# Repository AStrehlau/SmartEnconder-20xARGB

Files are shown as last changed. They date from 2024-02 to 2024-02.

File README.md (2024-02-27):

# SmartEncoder-20xARGB

This "SmartEncoder" uses 20 adressable LEDs (SK6805-EC15 or potentially XL-1615RGBC-WS2812B) to visualize the set point of the encoder. The SmartEncoder boasts WiFi and Bluetooth capability using the ESP32, which makes it viable for Smart Home and PC control applications.<br>
It should be noted that stock Windows does not normally have the capability to send the current volume level over BT, which is why a PC side software to take care of that will be uploaded  in the future for use as a BT PC volume knob.

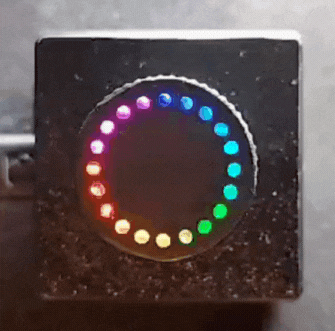
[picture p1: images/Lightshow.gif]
Lightshow


## Hardware

You can directly order the three PCBs needed for this project using the Gerber files (generated for JLCPCB but likely to work with most common providers) or modify the PCB files at your discretion and generate new Gerber files.

Each of the three PCBs have to be completely assembled before they can be stacked in the correct order using the 3D printed spacers and either wire or very long headers. For the assembly of the Top/LED PCB it is recommended if not necessary to order a stencil with the PCBs. The other PCBs can be assembled without one if so desired.

There is a complete BOM (except the very long headers/wire and M3x25m screws!) for all three PCBs and an interactive BOM for the PCB with the ESP32 on it. There is no ibom for the other two PCBs since every capacitor used on them is 100nF, every resistor on the encoder PCB is 10k and the one resistor on the LED PCB is 330R as can be seen in the schematics.<br>
The EMI filter on the ESP32 PCB (L1, L2 and C4) can be left out and Jumper JP1 soldered instead, although it is not recommended. Doing this has no effect on the functionality.<br>
Especially if you don't plan on running intensive animations on the LEDs the 20 bypass capacitors are definitely overkill (even though the datasheet might disagree). If you want to save on parts/ time spent placing them you can just place C14, C15 and C16 which was more than enough in my testing even just one of them might work for you.

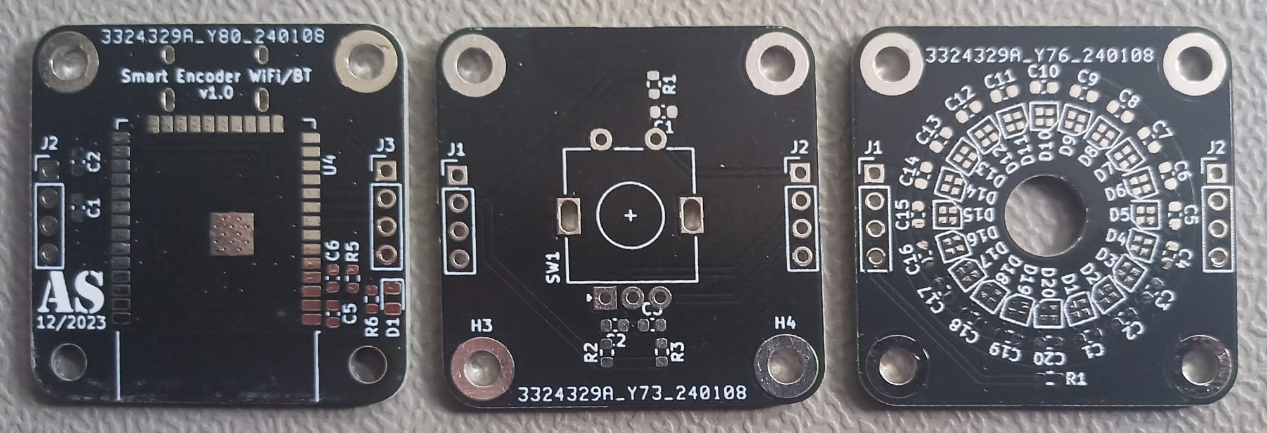
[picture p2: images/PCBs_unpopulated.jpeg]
Unpopulated PCBs


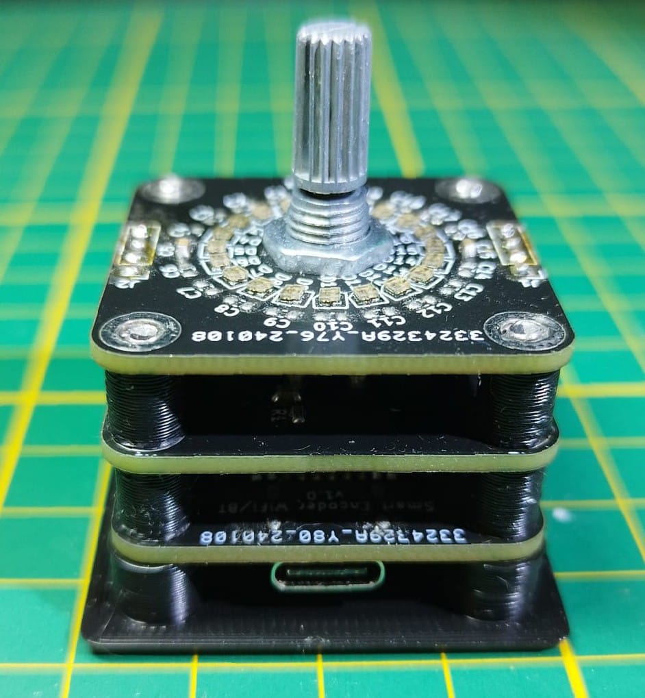
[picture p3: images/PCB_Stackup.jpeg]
PCBStackup


## 3D printed case

Thanks to [Nedos on Thingiverse](https://www.thingiverse.com/thing:6506406) designing a case including two knob versions for you to choose from and anti-bleed part for this project you can simply download the files and print them.<br>
The holes in the knob are meant to be filled with regular 1.75mm diameter transparent filament and either both surfaces cut flush using a side cutter or even sanded down for a better look.<br>
The anti-bleed part can simply be put on the LEDs making sure not to damage them.<br>
For assembly you only need the printed parts including spacers and M3x25mm screws, preferably with a flat underside.

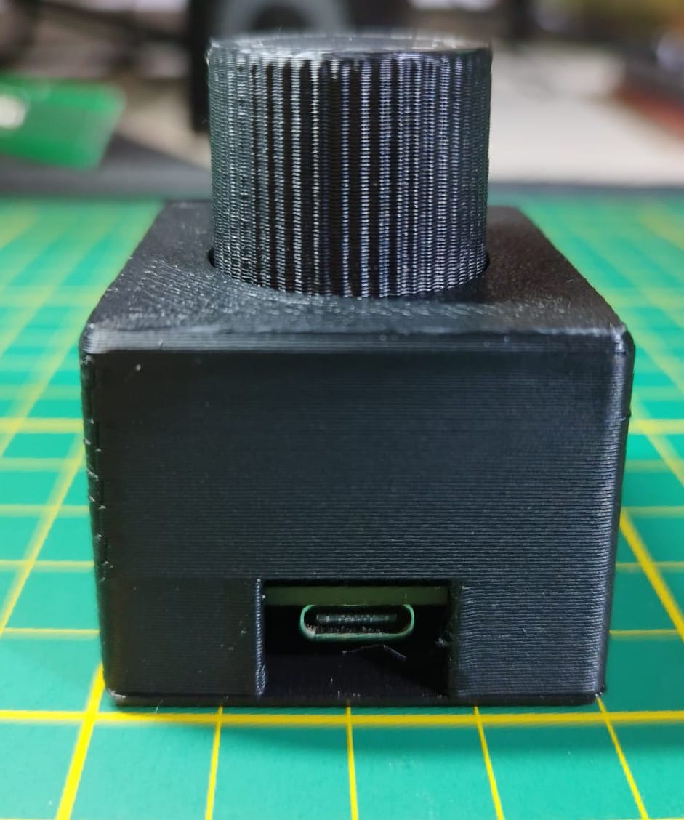
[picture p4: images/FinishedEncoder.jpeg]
Finished Encoder


## Software 

Because of layout reasons the LEDs have to be addressed in the opposite than expected order (LED number on the silkscreen is correct) which can result in longer code depending on the application.

There is a demo code for the LEDs which is just a slightly modified version of the Adafruit NEOPIXEL "strandtest" example to check if the LEDs are soldered correctly and undamaged as well as to give you a nice lightshow as can be seen at the top.<br>
This code can be flashed onto the ESP32 using the Arduino IDE.

Also available is a ESPHome configuration to integrate the SmartEncoder into HomeAssistant.

WIP: Code for ESP and PC to communicate via Serial over Bluetooth to use as a volume knob with accurate volume display on the SmartEncoder side

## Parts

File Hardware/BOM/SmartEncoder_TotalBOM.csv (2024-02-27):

Id | Footprint | Quantity | Designation | Supplier and ref
1 | R_0603_1608Metric | 6 | 10k
2 | C_0603_1608Metric | 3 | 1uF/10V/X5R
3 | C_0603_1608Metric | 24 | 100nF/10V/X7R
4 | ESP32-WROOM-32D | 1 | ESP32-WROOM-32D |  | NOTE: any ESP32-WROOM-32x works
5 | R_0603_1608Metric | 1 | 1k
6 | LED_0805_2012Metric | 1 | BLUE
7 | C_0603_1608Metric | 2 | 22uF/10V/X5R
8 | USB_C_Receptacle_HRO_TYPE-C-31-M-12 | 1 | USB_C_Receptacle_USB2.0 | SHOU HAN TYPE-C 16PIN 2MD(073)
9 | SolderJumper-2_P1.3mm_Open_RoundedPad1.0x1.5mm | 1 | SolderJumper_2_Open
10 | SOT-23-3 | 2 | MMBT4401
11 | R_0603_1608Metric | 1 | 15k
12 | L_0805_2012Metric | 2 | WLBD2012HCU601TH | WLBD2012HCU601TH or SBH2012S601NSP | SBH2012S601NSP is cheaper
13 | R_0603_1608Metric | 1 | 68k
14 | SOT-23-5 | 1 | M3406
15 | L_Abracon_ASPI-4030S | 1 | 2.2uH | SWPA4030S2R2
16 | SOIC-16_3.9x9.9mm_P1.27mm | 1 | CH340C
17 | R_0603_1608Metric | 2 | 5.1k
18 | RotaryEncoder_Alps_EC11E-Switch_Vertical_H20mm | 1 | RotaryEncoder_Switch |  | EC11 20mm „plum handle“
19 | SK6805-EC15 | 20 | SK6805-EC15 |  | NOTE: XL-1615RGBC-WS2812B !might! Work too and is cheaper
20 | R_0603_1608Metric | 1 | 330R

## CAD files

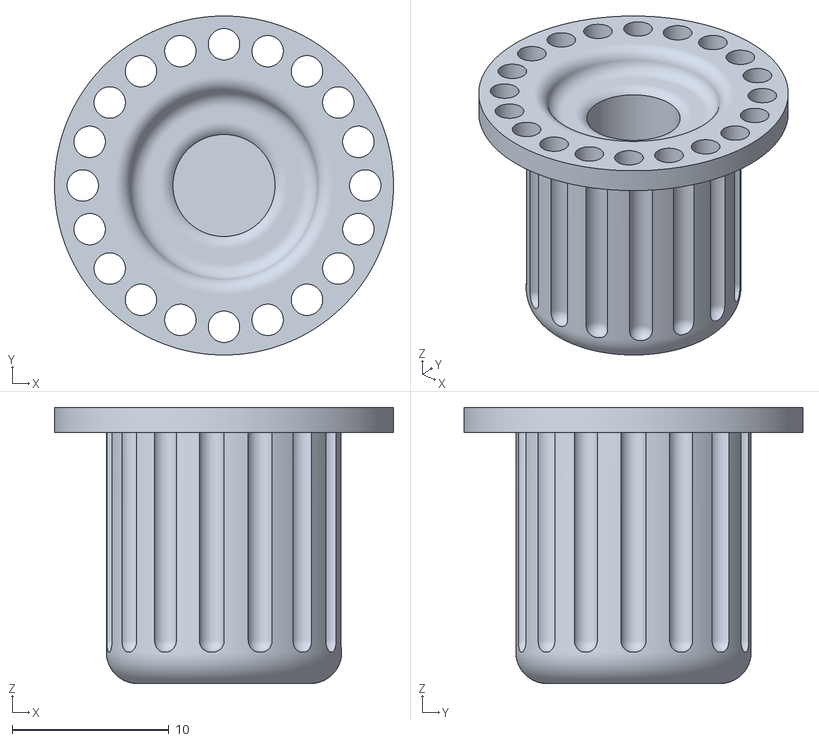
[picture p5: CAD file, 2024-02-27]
3D/KnobSmall.stl
21.6 x 21.6 x 17.6

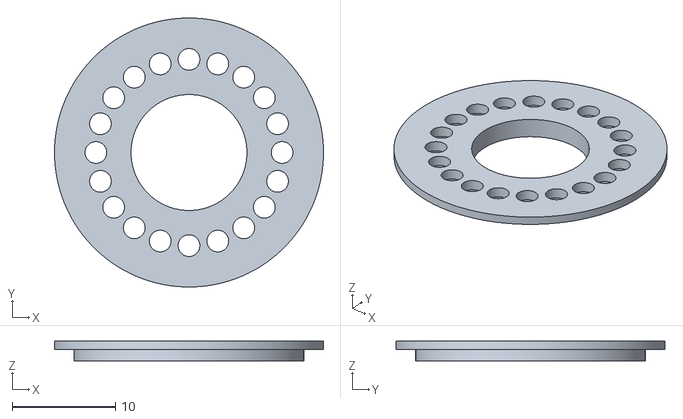
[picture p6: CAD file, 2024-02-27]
3D/AntiBleed.stl
26.0 x 26.0 x 1.90

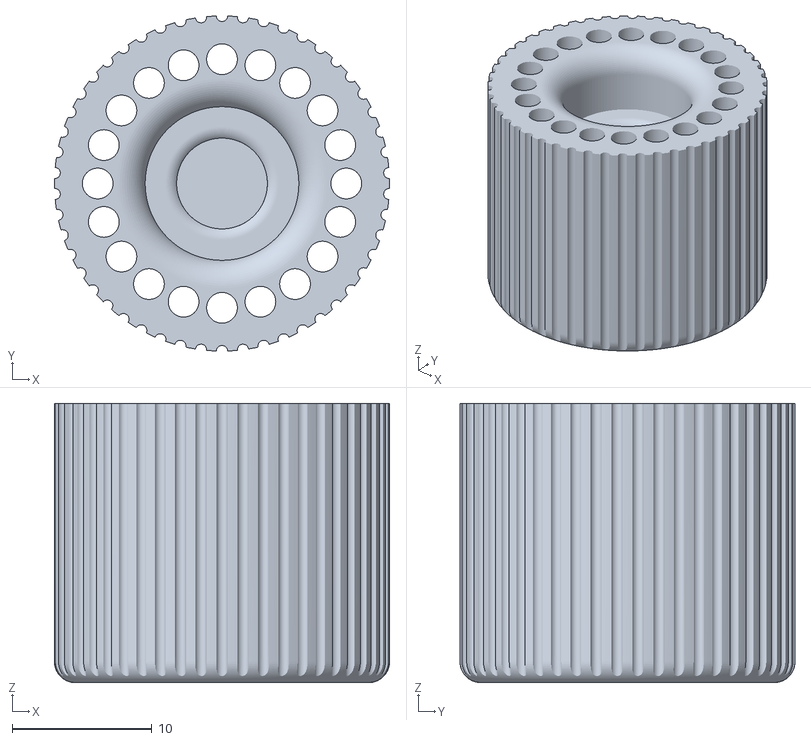
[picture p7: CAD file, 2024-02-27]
3D/KnobBig.stl
24.0 x 24.0 x 20.0

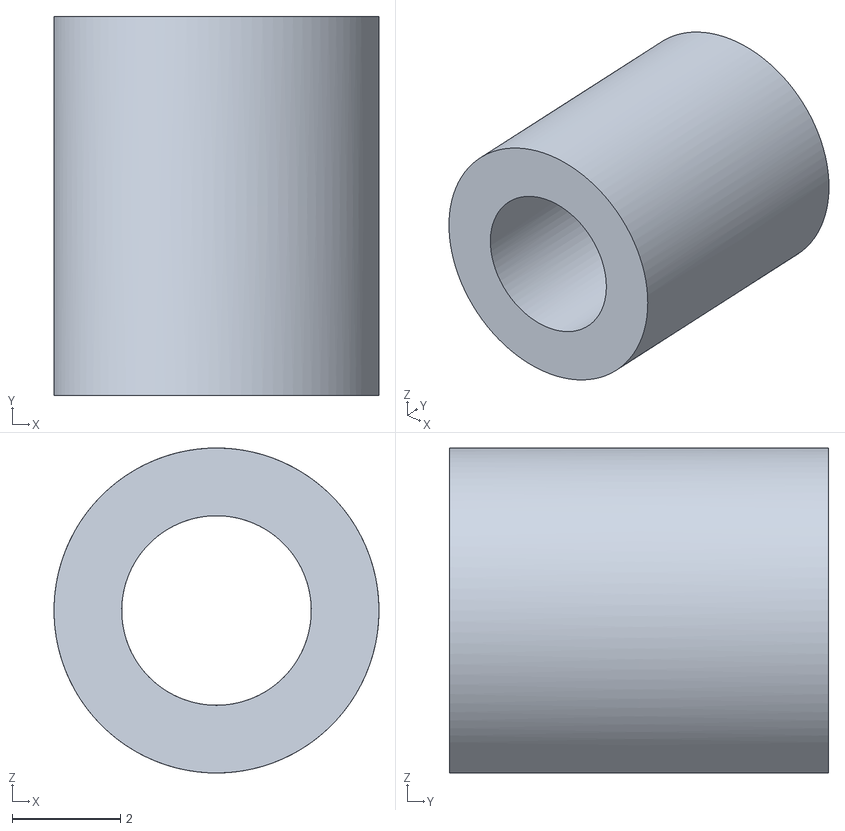
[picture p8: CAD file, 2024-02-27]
3D/Spacerx8.stl
6.00 x 7.00 x 6.00

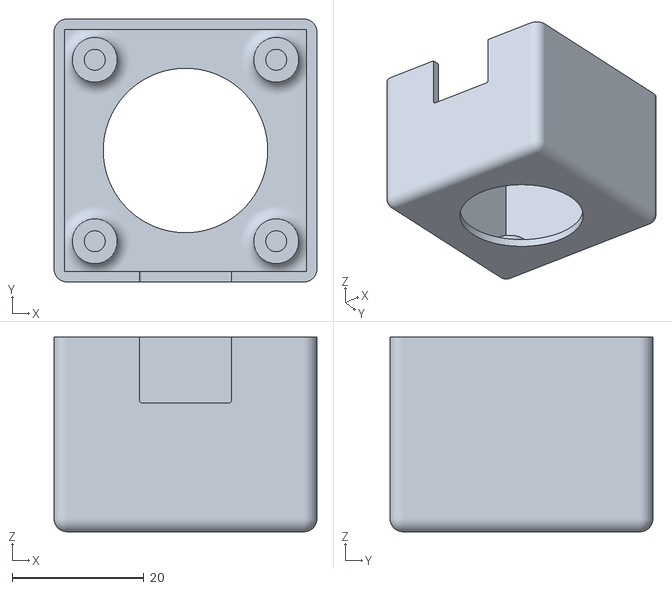
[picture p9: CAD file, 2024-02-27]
3D/SmartEncoderCase.stl
40.0 x 40.0 x 29.6

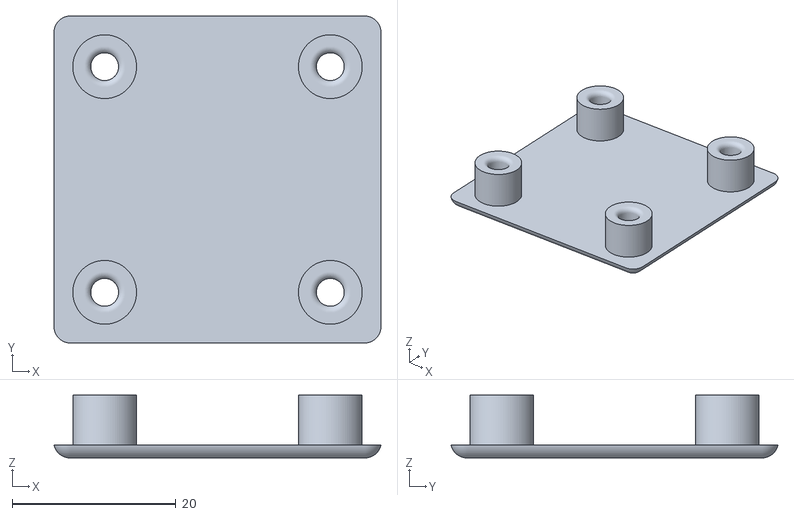
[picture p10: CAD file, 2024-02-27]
3D/SmartEncoderLid.stl
40.0 x 40.0 x 7.70

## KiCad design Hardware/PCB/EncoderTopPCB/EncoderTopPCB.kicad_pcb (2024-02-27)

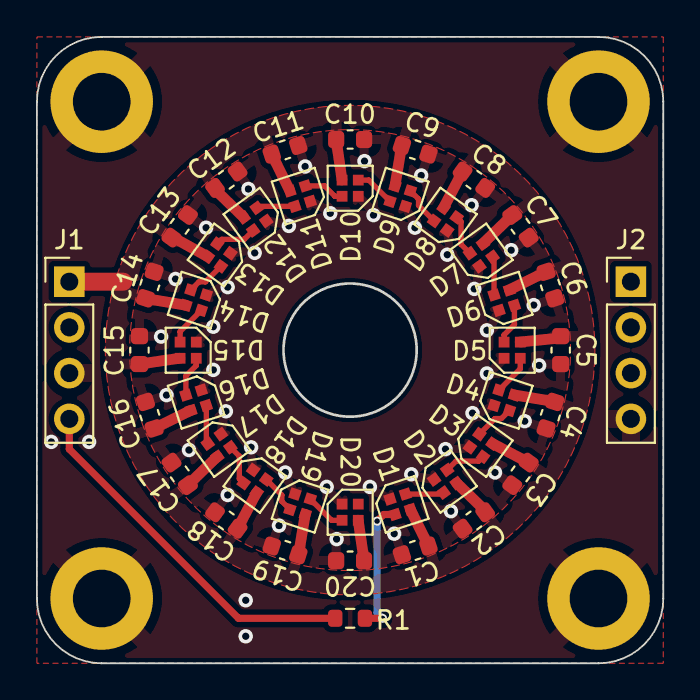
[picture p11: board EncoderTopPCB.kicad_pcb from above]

Board: 2 copper layers, 34.8 x 34.8 mm, 47 parts (0 on the bottom side), 23 nets.

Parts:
C1, C2, C3, C4, C5, C6, C7, C8, C9, C10, C11, C12, C13, C14, C15, C16, C17, C18, C19, C20: 10V/100nF/X7R; C_0603_1608Metric
D1, D2, D3, D4, D5, D6, D7, D8, D9, D10, D11, D12, D13, D14, D15, D16, D17, D18, D19, D20: SK6805; SK6805-EC15
H1, H2, H3, H4: DNP; MountingHole_3.2mm_M3_ISO7380_Pad
J1, J2: DNP; PinHeader_1x04_P2.54mm_Vertical
R1: 330R; R_0603_1608Metric

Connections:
+5V: C1.1, C2.1, C3.1, C4.1, C5.1, C6.1, C7.1, C8.1, C9.1, C10.1, C11.1, C12.1, C13.1, C14.1, C15.1, C16.1, C17.1, C18.1, C19.1, C20.1, D1.2 (VDD), D2.2 (VDD), D3.2 (VDD), D4.2 (VDD), D5.2 (VDD), D6.2 (VDD), D7.2 (VDD), D8.2 (VDD), D9.2 (VDD), D10.2 (VDD), D11.2 (VDD), D12.2 (VDD), D13.2 (VDD), D14.2 (VDD), D15.2 (VDD), D16.2 (VDD), D17.2 (VDD), D18.2 (VDD), D19.2 (VDD), D20.2 (VDD), J1.1
GND: C1.2, C2.2, C3.2, C4.2, C5.2, C6.2, C7.2, C8.2, C9.2, C10.2, C11.2, C12.2, C13.2, C14.2, C15.2, C16.2, C17.2, C18.2, C19.2, C20.2, D1.4 (VSS), D2.4 (VSS), D3.4 (VSS), D4.4 (VSS), D5.4 (VSS), D6.4 (VSS), D7.4 (VSS), D8.4 (VSS), D9.4 (VSS), D10.4 (VSS), D11.4 (VSS), D12.4 (VSS), D13.4 (VSS), D14.4 (VSS), D15.4 (VSS), D16.4 (VSS), D17.4 (VSS), D18.4 (VSS), D19.4 (VSS), D20.4 (VSS), H1.1, H2.1, H3.1, H4.1, J1.3, J2.4
IO3: J1.4, R1.1
unnamed: D1.1 (DIN), R1.2
unnamed: D1.3 (DOUT), D2.1 (DIN)
unnamed: D2.3 (DOUT), D3.1 (DIN)
unnamed: D3.3 (DOUT), D4.1 (DIN)
unnamed: D4.3 (DOUT), D5.1 (DIN)
unnamed: D5.3 (DOUT), D6.1 (DIN)
unnamed: D6.3 (DOUT), D7.1 (DIN)
unnamed: D7.3 (DOUT), D8.1 (DIN)
unnamed: D8.3 (DOUT), D9.1 (DIN)
unnamed: D9.3 (DOUT), D10.1 (DIN)
unnamed: D10.3 (DOUT), D11.1 (DIN)
unnamed: D11.3 (DOUT), D12.1 (DIN)
unnamed: D12.3 (DOUT), D13.1 (DIN)
unnamed: D13.3 (DOUT), D14.1 (DIN)
unnamed: D14.3 (DOUT), D15.1 (DIN)
unnamed: D15.3 (DOUT), D16.1 (DIN)
unnamed: D16.3 (DOUT), D17.1 (DIN)
unnamed: D17.3 (DOUT), D18.1 (DIN)
unnamed: D18.3 (DOUT), D19.1 (DIN)
unnamed: D19.3 (DOUT), D20.1 (DIN)

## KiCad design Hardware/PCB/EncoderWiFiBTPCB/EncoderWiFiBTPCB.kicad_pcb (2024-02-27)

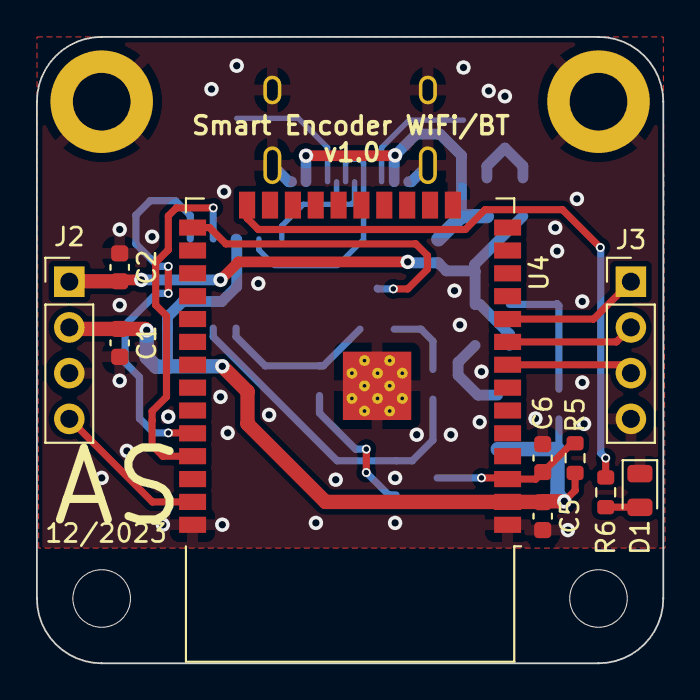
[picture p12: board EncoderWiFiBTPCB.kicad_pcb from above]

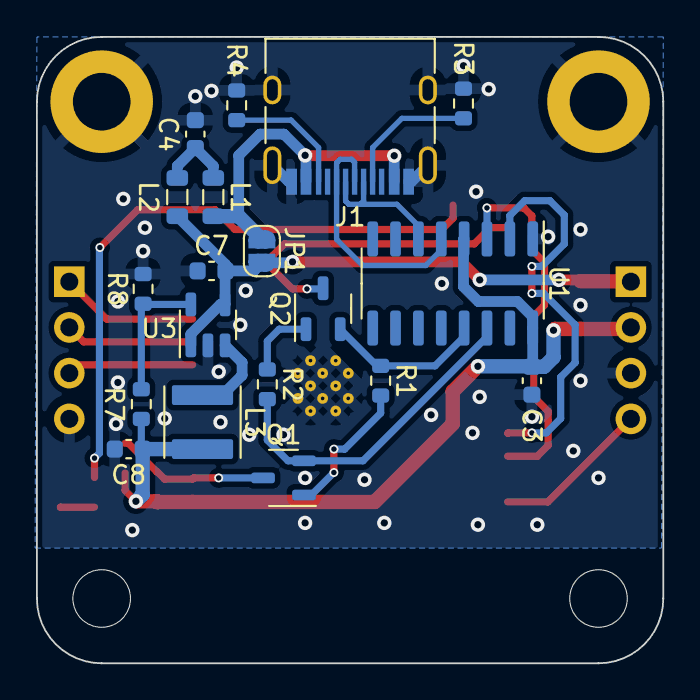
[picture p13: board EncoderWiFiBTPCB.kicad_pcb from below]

Board: 2 copper layers, 34.8 x 34.8 mm, 33 parts (19 on the bottom side), 25 nets.

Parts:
C1, C2, C4: 1uF/25V/X5R; C_0603_1608Metric
C3, C5, C6: 100nF/10V/X7R; C_0603_1608Metric
C7, C8: 22uF/10V/X5R; C_0603_1608Metric
D1: BLUE; LED_0805_2012Metric
H1, H2: MountingHole_Pad; MountingHole_3.2mm_M3_ISO7380_Pad
H3, H4: MountingHole; MountingHole_3.2mm_M3_ISO7380
J1: USB_C_Receptacle_USB2.0; USB_C_Receptacle_HRO_TYPE-C-31-M-12
J2, J3: Conn_01x04_Pin; PinHeader_1x04_P2.54mm_Vertical
JP1: SolderJumper_2_Open; SolderJumper-2_P1.3mm_Open_RoundedPad1.0x1.5mm
L1, L2: WLBD2012HCU601TH; L_0805_2012Metric
L3: 2.2uH; L_Abracon_ASPI-4030S
Q1, Q2: MMBT4401; SOT-23-3
R1, R2, R5: 10k; R_0603_1608Metric
R3, R4: 5.1k; R_0603_1608Metric
R6: 1k; R_0603_1608Metric
R7: 68k; R_0603_1608Metric
R8: 15k; R_0603_1608Metric
U1: CH340C; SOIC-16_3.9x9.9mm_P1.27mm
U3: M3406; SOT-23-5
U4: ESP32-WROOM-32D

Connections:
+3V3: C1.1, C3.1, C5.2, C8.1, J2.2, L3.2, R5.2, R7.1, U1.4 (V3), U1.16 (VCC), U4.2 (VDD)
+5V: C2.1, C7.1, J2.1, JP1.2 (B), L2.2, U3.1 (RUN), U3.4 (VIN)
D+: J1.A6 (D+), J1.B6 (D+), U1.5 (UD+)
D-: J1.A7 (D-), J1.B7 (D-), U1.6 (UD-)
ENCODER_A: J3.2, U4.9 (IO33)
ENCODER_B: J3.3, U4.8 (IO32)
ENCODER_BTN: J3.1, U4.10 (IO25)
GND: C1.2, C2.2, C3.2, C4.2, C5.1, C6.1, C7.2, C8.2, D1.1 (K), H1.1, H2.1, J1.A1 (GND), J1.A12 (GND), J1.B1 (GND), J1.B12 (GND), J1.S1 (SHIELD), J2.3, J3.4, R3.2, R4.2, R8.2, U1.1 (GND), U3.2 (GND), U4.1 (GND), U4.15 (GND), U4.38 (GND), U4.39 (GND)
IO23: J2.4, U4.37 (IO23)
unnamed: C4.1, L1.2, L2.1
unnamed: D1.2 (A), R6.1
unnamed: J1.A5 (CC1), R3.1
unnamed: J1.B5 (CC2), R4.1
unnamed: J1.A4 (VBUS), J1.A9 (VBUS), J1.B4 (VBUS), J1.B9 (VBUS), JP1.1 (A), L1.1
unnamed: Q1.1 (B), R1.2
unnamed: Q1.2 (E), R2.1, U1.14 (~RTS)
unnamed: Q2.1 (B), R2.2
unnamed: Q2.2 (E), R1.1, U1.13 (~DTR)
unnamed: R7.2, R8.1, U3.5 (FB)
unnamed: L3.1, U3.3 (SW)
unnamed: R6.2, U4.24 (IO2)
RX0 (Programming): U1.2 (TXD), U4.34 (RXD0/IO3)
TX0 (Programming): U1.3 (RXD), U4.35 (TXD0/IO1)
~BOOTMODE: Q2.3 (C), U4.25 (IO0)
~RST: C6.2, Q1.3 (C), R5.1, U4.3 (EN)

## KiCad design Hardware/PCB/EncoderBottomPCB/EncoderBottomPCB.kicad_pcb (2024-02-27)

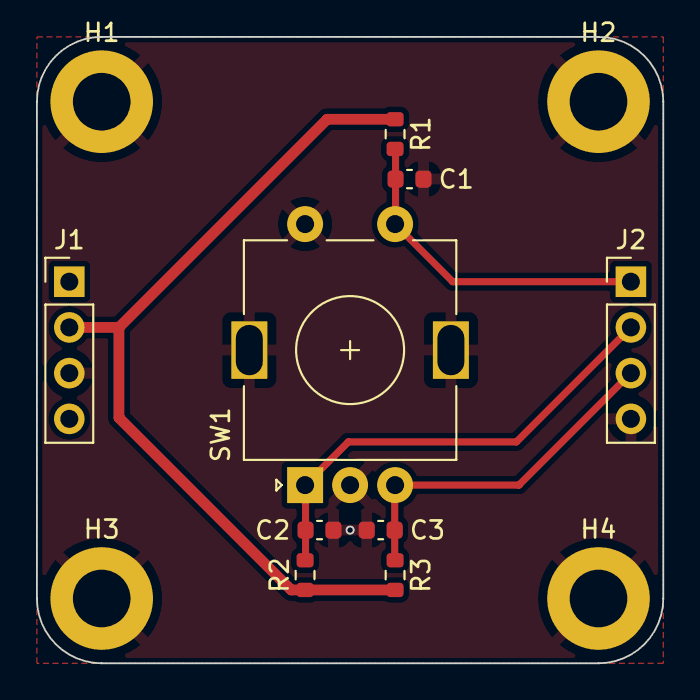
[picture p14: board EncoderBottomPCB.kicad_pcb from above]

Board: 2 copper layers, 34.8 x 34.8 mm, 13 parts (0 on the bottom side), 5 nets.

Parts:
C1, C2, C3: 100nF/10V/X7R; C_0603_1608Metric
H1, H2, H3, H4: MountingHole_Pad; MountingHole_3.2mm_M3_ISO7380_Pad
J1, J2: Conn_01x04_Pin; PinHeader_1x04_P2.54mm_Vertical
R1, R2, R3: 10k; R_0603_1608Metric
SW1: RotaryEncoder_Switch; RotaryEncoder_Alps_EC11E-Switch_Vertical_H20mm

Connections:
+3V3: J1.2, R1.1, R2.1, R3.2
ENCODER_A: C2.2, J2.2, R2.2, SW1.A
ENCODER_B: C3.2, J2.3, R3.1, SW1.B
ENCODER_BTN: C1.2, J2.1, R1.2, SW1.S1
GND: C1.1, C2.1, C3.1, H1.1, H2.1, H3.1, H4.1, J1.3, J2.4, SW1.C, SW1.MP, SW1.S2

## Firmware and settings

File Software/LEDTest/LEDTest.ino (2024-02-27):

// A basic everyday NeoPixel strip test program.

// NEOPIXEL BEST PRACTICES for most reliable operation:
// - Add 1000 uF CAPACITOR between NeoPixel strip's + and - connections.
// - MINIMIZE WIRING LENGTH between microcontroller board and first pixel.
// - NeoPixel strip's DATA-IN should pass through a 300-500 OHM RESISTOR.
// - AVOID connecting NeoPixels on a LIVE CIRCUIT. If you must, ALWAYS
//   connect GROUND (-) first, then +, then data.
// - When using a 3.3V microcontroller with a 5V-powered NeoPixel strip,
//   a LOGIC-LEVEL CONVERTER on the data line is STRONGLY RECOMMENDED.
// (Skipping these may work OK on your workbench but can fail in the field)

#include <Adafruit_NeoPixel.h>
#ifdef __AVR__
 #include <avr/power.h> // Required for 16 MHz Adafruit Trinket
#endif

// Which pin on the Arduino is connected to the NeoPixels?
// On a Trinket or Gemma we suggest changing this to 1:
#define LED_PIN    23

// How many NeoPixels are attached to the Arduino?
#define LED_COUNT 20

// Declare our NeoPixel strip object:
Adafruit_NeoPixel strip(LED_COUNT, LED_PIN, NEO_GRB + NEO_KHZ800);
// Argument 1 = Number of pixels in NeoPixel strip
// Argument 2 = Arduino pin number (most are valid)
// Argument 3 = Pixel type flags, add together as needed:
//   NEO_KHZ800  800 KHz bitstream (most NeoPixel products w/WS2812 LEDs)
//   NEO_KHZ400  400 KHz (classic 'v1' (not v2) FLORA pixels, WS2811 drivers)
//   NEO_GRB     Pixels are wired for GRB bitstream (most NeoPixel products)
//   NEO_RGB     Pixels are wired for RGB bitstream (v1 FLORA pixels, not v2)
//   NEO_RGBW    Pixels are wired for RGBW bitstream (NeoPixel RGBW products)


// setup() function -- runs once at startup --------------------------------

void setup() {
  // These lines are specifically to support the Adafruit Trinket 5V 16 MHz.
  // Any other board, you can remove this part (but no harm leaving it):
#if defined(__AVR_ATtiny85__) && (F_CPU == 16000000)
  clock_prescale_set(clock_div_1);
#endif
  // END of Trinket-specific code.

  strip.begin();           // INITIALIZE NeoPixel strip object (REQUIRED)
  strip.show();            // Turn OFF all pixels ASAP
  strip.setBrightness(30); // Set BRIGHTNESS to about 1/5 (max = 255)
}


// loop() function -- runs repeatedly as long as board is on ---------------

void loop() {
  // Fill along the length of the strip in various colors...
  colorWipe(strip.Color(255,   0,   0), 50); // Red
  colorWipe(strip.Color(  0, 255,   0), 50); // Green
  colorWipe(strip.Color(  0,   0, 255), 50); // Blue

  // Do a theater marquee effect in various colors...
  theaterChase(strip.Color(127, 127, 127), 50); // White, half brightness
  theaterChase(strip.Color(127,   0,   0), 50); // Red, half brightness
  theaterChase(strip.Color(  0,   0, 127), 50); // Blue, half brightness

  rainbow(10);             // Flowing rainbow cycle along the whole strip
  theaterChaseRainbow(50); // Rainbow-enhanced theaterChase variant
}


// Some functions of our own for creating animated effects -----------------

// Fill strip pixels one after another with a color. Strip is NOT cleared
// first; anything there will be covered pixel by pixel. Pass in color
// (as a single 'packed' 32-bit value, which you can get by calling
// strip.Color(red, green, blue) as shown in the loop() function above),
// and a delay time (in milliseconds) between pixels.
void colorWipe(uint32_t color, int wait) {
  for(int i=0; i<strip.numPixels(); i++) { // For each pixel in strip...
    strip.setPixelColor(i, color);         //  Set pixel's color (in RAM)
    strip.show();                          //  Update strip to match
    delay(wait);                           //  Pause for a moment
  }
}

// Theater-marquee-style chasing lights. Pass in a color (32-bit value,
// a la strip.Color(r,g,b) as mentioned above), and a delay time (in ms)
// between frames.
void theaterChase(uint32_t color, int wait) {
  for(int a=0; a<10; a++) {  // Repeat 10 times...
    for(int b=0; b<3; b++) { //  'b' counts from 0 to 2...
      strip.clear();         //   Set all pixels in RAM to 0 (off)
      // 'c' counts up from 'b' to end of strip in steps of 3...
      for(int c=b; c<strip.numPixels(); c += 3) {
        strip.setPixelColor(c, color); // Set pixel 'c' to value 'color'
      }
      strip.show(); // Update strip with new contents
      delay(wait);  // Pause for a moment
    }
  }
}

// Rainbow cycle along whole strip. Pass delay time (in ms) between frames.
void rainbow(int wait) {
  // Hue of first pixel runs 5 complete loops through the color wheel.
  // Color wheel has a range of 65536 but it's OK if we roll over, so
  // just count from 0 to 5*65536. Adding 256 to firstPixelHue each time
  // means we'll make 5*65536/256 = 1280 passes through this loop:
  for(long firstPixelHue = 0; firstPixelHue < 5*65536; firstPixelHue += 256) {
    // strip.rainbow() can take a single argument (first pixel hue) or
    // optionally a few extras: number of rainbow repetitions (default 1),
    // saturation and value (brightness) (both 0-255, similar to the
    // ColorHSV() function, default 255), and a true/false flag for whether
    // to apply gamma correction to provide 'truer' colors (default true).
    strip.rainbow(firstPixelHue);
    // Above line is equivalent to:
    // strip.rainbow(firstPixelHue, 1, 255, 255, true);
    strip.show(); // Update strip with new contents
    delay(wait);  // Pause for a moment
  }
}

// Rainbow-enhanced theater marquee. Pass delay time (in ms) between frames.
void theaterChaseRainbow(int wait) {
  int firstPixelHue = 0;     // First pixel starts at red (hue 0)
  for(int a=0; a<30; a++) {  // Repeat 30 times...
    for(int b=0; b<3; b++) { //  'b' counts from 0 to 2...
      strip.clear();         //   Set all pixels in RAM to 0 (off)
      // 'c' counts up from 'b' to end of strip in increments of 3...
      for(int c=b; c<strip.numPixels(); c += 3) {
        // hue of pixel 'c' is offset by an amount to make one full
        // revolution of the color wheel (range 65536) along the length
        // of the strip (strip.numPixels() steps):
        int      hue   = firstPixelHue + c * 65536L / strip.numPixels();
        uint32_t color = strip.gamma32(strip.ColorHSV(hue)); // hue -> RGB
        strip.setPixelColor(c, color); // Set pixel 'c' to value 'color'
      }
      strip.show();                // Update strip with new contents
      delay(wait);                 // Pause for a moment
      firstPixelHue += 65536 / 90; // One cycle of color wheel over 90 frames
    }
  }
}
